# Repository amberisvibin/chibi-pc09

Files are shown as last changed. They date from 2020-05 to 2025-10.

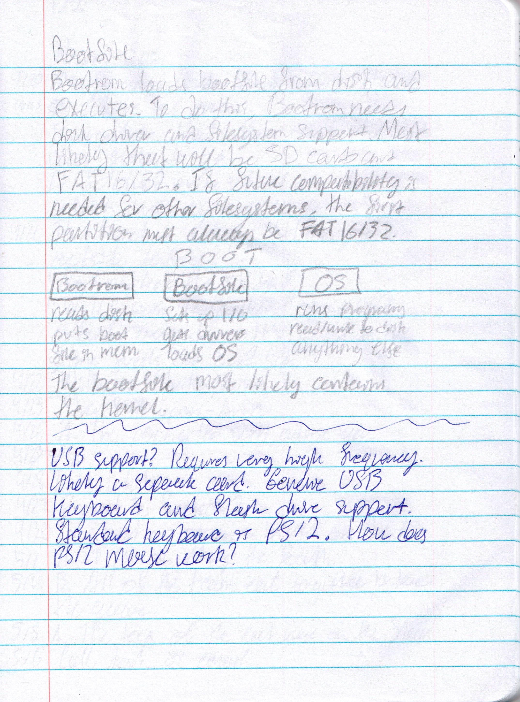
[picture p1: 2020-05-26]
docs/design notes/BR_Z800005.jpg

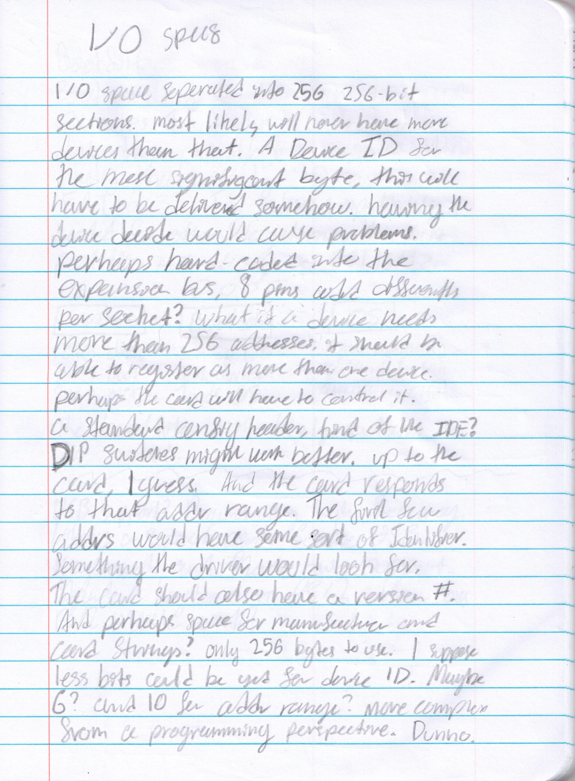
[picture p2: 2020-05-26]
docs/design notes/BR_Z800004.jpg

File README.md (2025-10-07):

# chibi pc-09

## Archived!

This repo has been archived, and the different parts have been migrated to other repos.

The PCB for prototype 1 has been moved to https://gitea.ambersplace.net/chibi/pc09-prototype-1

The firmware has been moved to https://gitea.ambersplace.net/chibi/chibi-firmware




## Description

The PC-09 will be a 6309 based microcomputer with an MMU using 74HC670 register files and dual 16550 UARTs. The plan is to eventually add uPD7220 graphics and PS/2 mouse and keyboard.

The two 74HC670s will take the top 4 bits of the address bus and expand them to 8 bits, turning the 16 bit cpu address space into a 20 bit address space capable of addressing 1MB of memory. Memory pages are 4KB. Being a register file, any page can be mapped to any slot, allowing complex memory management schemes.

The 16550 UART is capable of interrupt driven operation with FIFOs, allowing for characters to be processed in batches rather than individually, minimizing task switch delays. They also support hardware flow control, and some versions can automatically assert RTS when the FIFO is nearing full.

The uPD7220 graphics are very powerful, allowing 16 colors at 640x480, but it is a complex chip to get working. It will be left for a later date.

The solution for PS/2 keyboard and mouse have not yet been decided.

## Progress

I had started wiring together a board for prototyping, but it was destroyed in hurricane Helene. I am now recreating it in schematic form in order to order a PCB.

Prototype 1 is currently in progress. It will be a much simpler system. It will have no MMU, just the CPU, some RAM, some ROM, and the UART.

The PCB and parts for Prototype #1 have been ordered, and assembly will begin soon. Initial test code is now available in the code/ directory.

Assembly is in progress.

## License

This project is licensed under the MIT license. This applies to both the hardware (schematics, bill of materials, pcb layouts) and documentation. This does *not* apply to the datasheets/ directory or code/assist09/. Those files belong to their respective copyright holders.

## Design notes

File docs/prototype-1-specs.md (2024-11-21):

# 6309 Board Prototype #1 Specs

HD63C09 CPU @ 3MHz
AS6C62256-55 SRAM (32KB)
SST39SF010A-70 FLASH (32KB Used)
PC16550 UART @ 1.8342MHz

## Memory Map

| Device | Location  |
|---|---|
| FLASH  | 8000-FFFF |
| UART | 7F00-7FFF |
| SRAM | 0000-7EFF |

## Truth Table

| A15 | A14-A9 | A8 | Chip |
|-----|---|----|---|
| H | x | x  | FLASH  |
| L | x | L  | SRAM |
| L | H | H  | UART |

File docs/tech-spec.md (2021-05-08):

# CHIBI PC-09 Technical Specification

5-17-21 Amber Zeller

## Quick Specs

#### CPU

1, 1.5, 2 MHz Motorola 6809

#### Memory

64k SRAM on external card for optional MMU capability. Seperated into 2k blocks, numbered 0-31. Only 62k of memory is accessible, due to the I/O block.

#### I/O

2k block, position 30. Addresses EFFF-F7FE. Further subdivided into 128 devices of 16 addresses each. 

## Address Space Diagram

| Address Range | Description |
| --- | --- |
| 0000 - 07FF | Kernal Root Block |
| 0800 - EFFE | Standard Memory Blocks |
| EFFF - F7FE | I/O Block |
| F7FF - FFFF | Vector Block |

## I/O Block Description

11 bits per block

128 devices are possible, though will likely never be used. 

| Bits | Description |
| ---- | --- |
| 0-6  | Device selection  |
| 7-10 | Address selection |

## Expansion Card Description

Byte 0 of every card should contain a descriptor. The structure of the descriptor is described in the following table.

| Bits | Descriptor |
| ---- | --- |
| 0-2  | Type |

### Type Descriptor Table

| Type Descriptor | Description | Example  |
| --- | --- | --- |
| 000 | Block Storage | SD Card  |
| 001 | ANSI I/O Stream | UART |
| 010 | ANSI Compatible Graphics Device | VGA64 |
| 011 | Input Device | Keyboard |
| 1xx | Other | Other |

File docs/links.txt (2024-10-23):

uPD7220 graphics card
https://hackaday.io/project/164728/logs

16550 to 6502
https://www.cs.cornell.edu/~kt/post/6502-5/

VT82C42 to 65816
http://www.baltissen.org/newhtm/65816atx.htm

6502.org post about CMOS/TTL driving voltage
http://forum.6502.org/viewtopic.php?f=4&t=3477

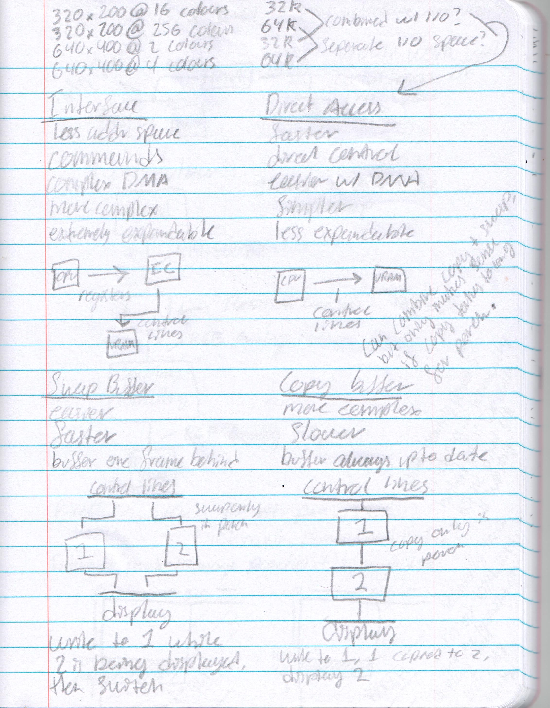
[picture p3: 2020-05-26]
docs/design notes/BR_Z80.jpg

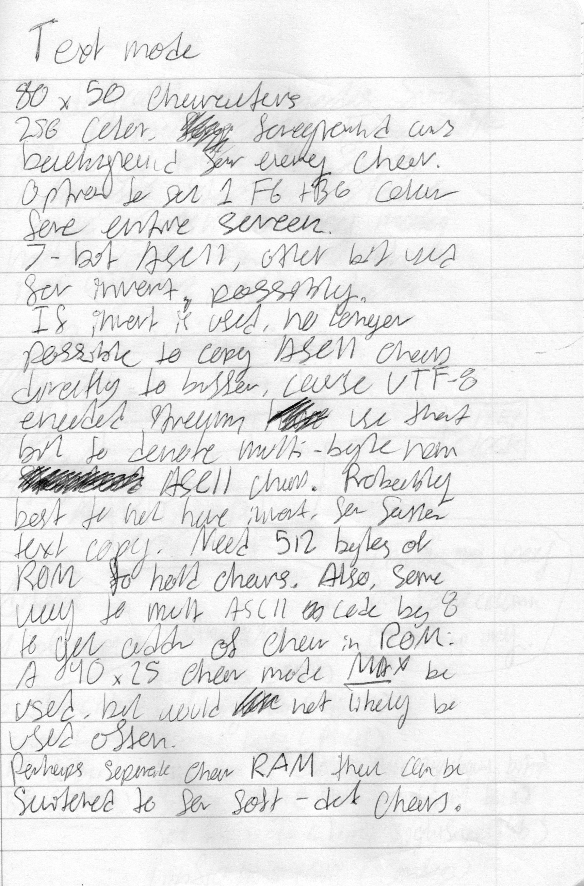
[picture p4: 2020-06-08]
docs/design notes/BR_Z800006.jpg

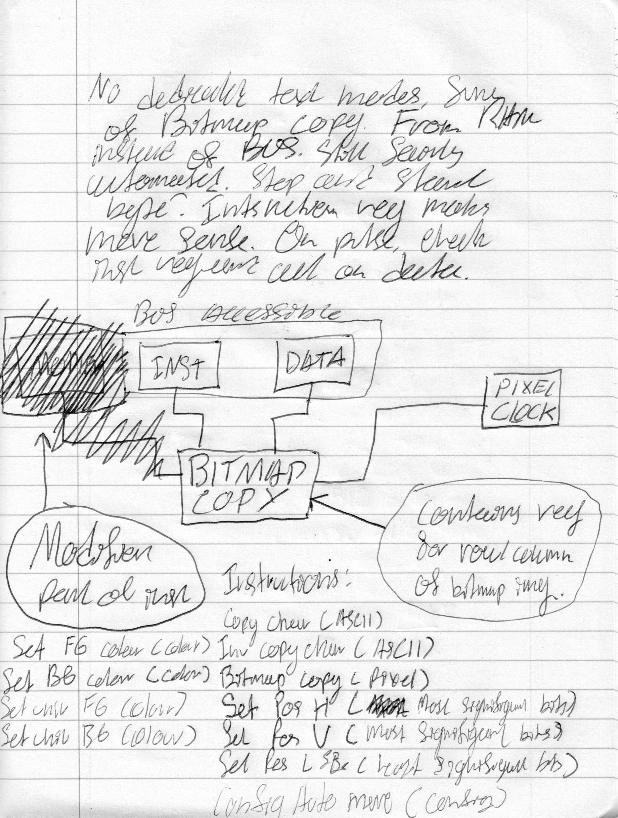
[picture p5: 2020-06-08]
docs/design notes/BR_Z800007.jpg

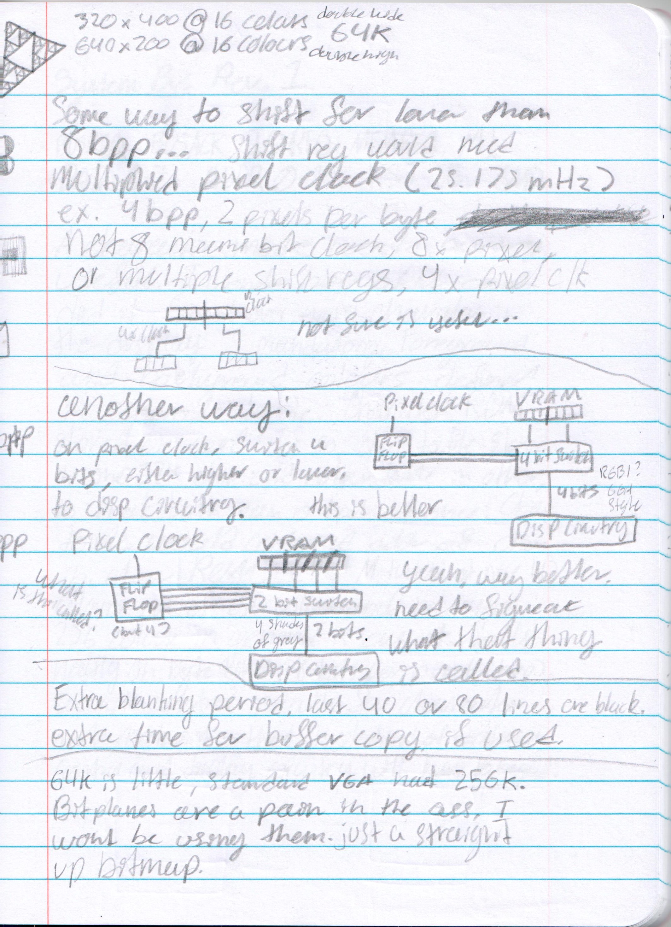
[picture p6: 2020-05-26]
docs/design notes/BR_Z800002.jpg

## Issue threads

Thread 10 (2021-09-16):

mpl does not fit

amberisvibin, 2021-09-16:
this issue will act as a repo for MPL licensing issues

### problems:

- MPL doesnt apply well to schematics and open source hardware
- need to determine how to do documentation license
- MPL must be applied on a file-by-file level (less important)

### potential solutions:

- separate licenses for different parts
- split into multiple repos

amberisvibin, 2024-10-22:
fixed in #cb9a218

Closed 2024-10-22.

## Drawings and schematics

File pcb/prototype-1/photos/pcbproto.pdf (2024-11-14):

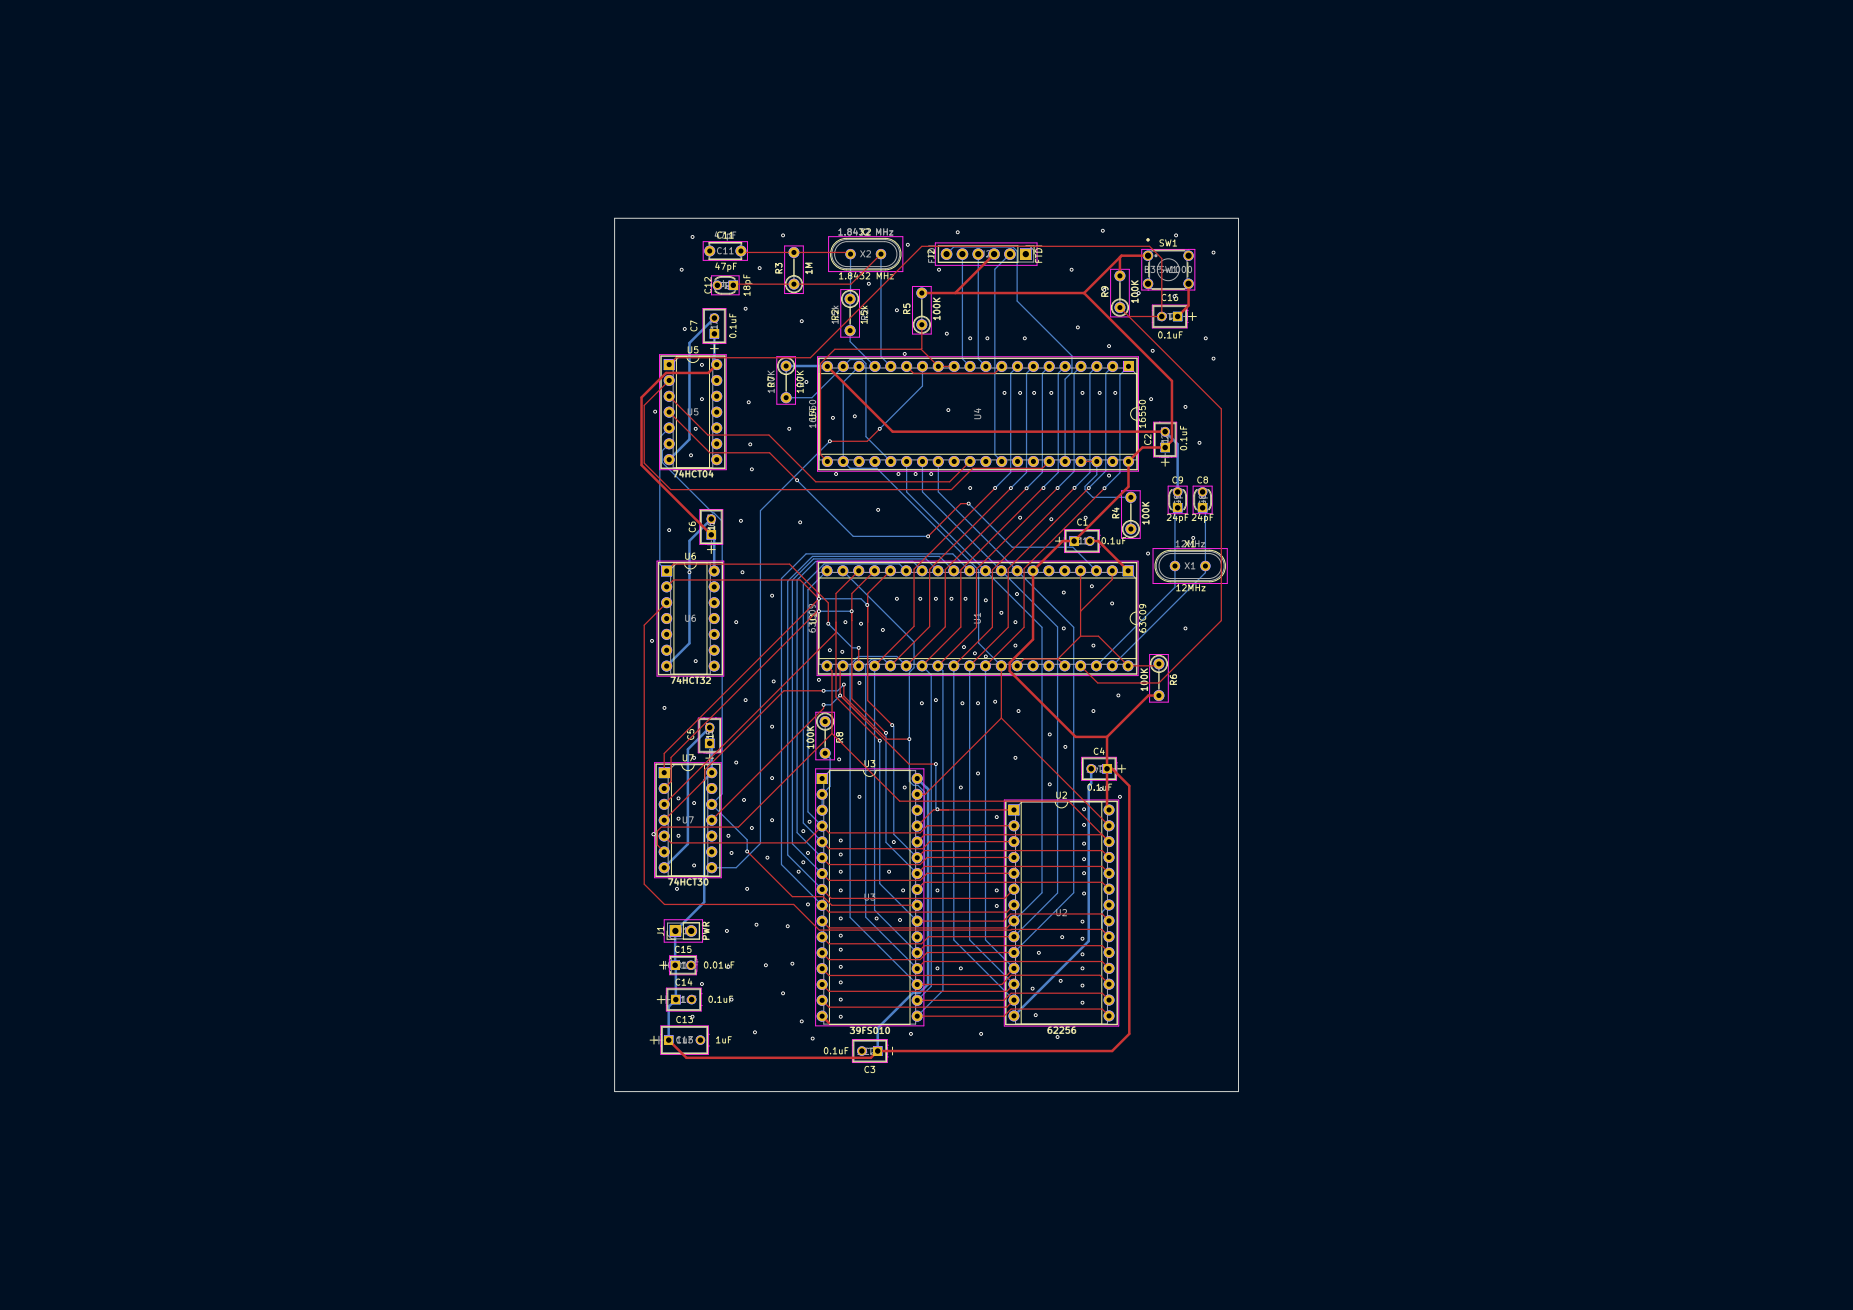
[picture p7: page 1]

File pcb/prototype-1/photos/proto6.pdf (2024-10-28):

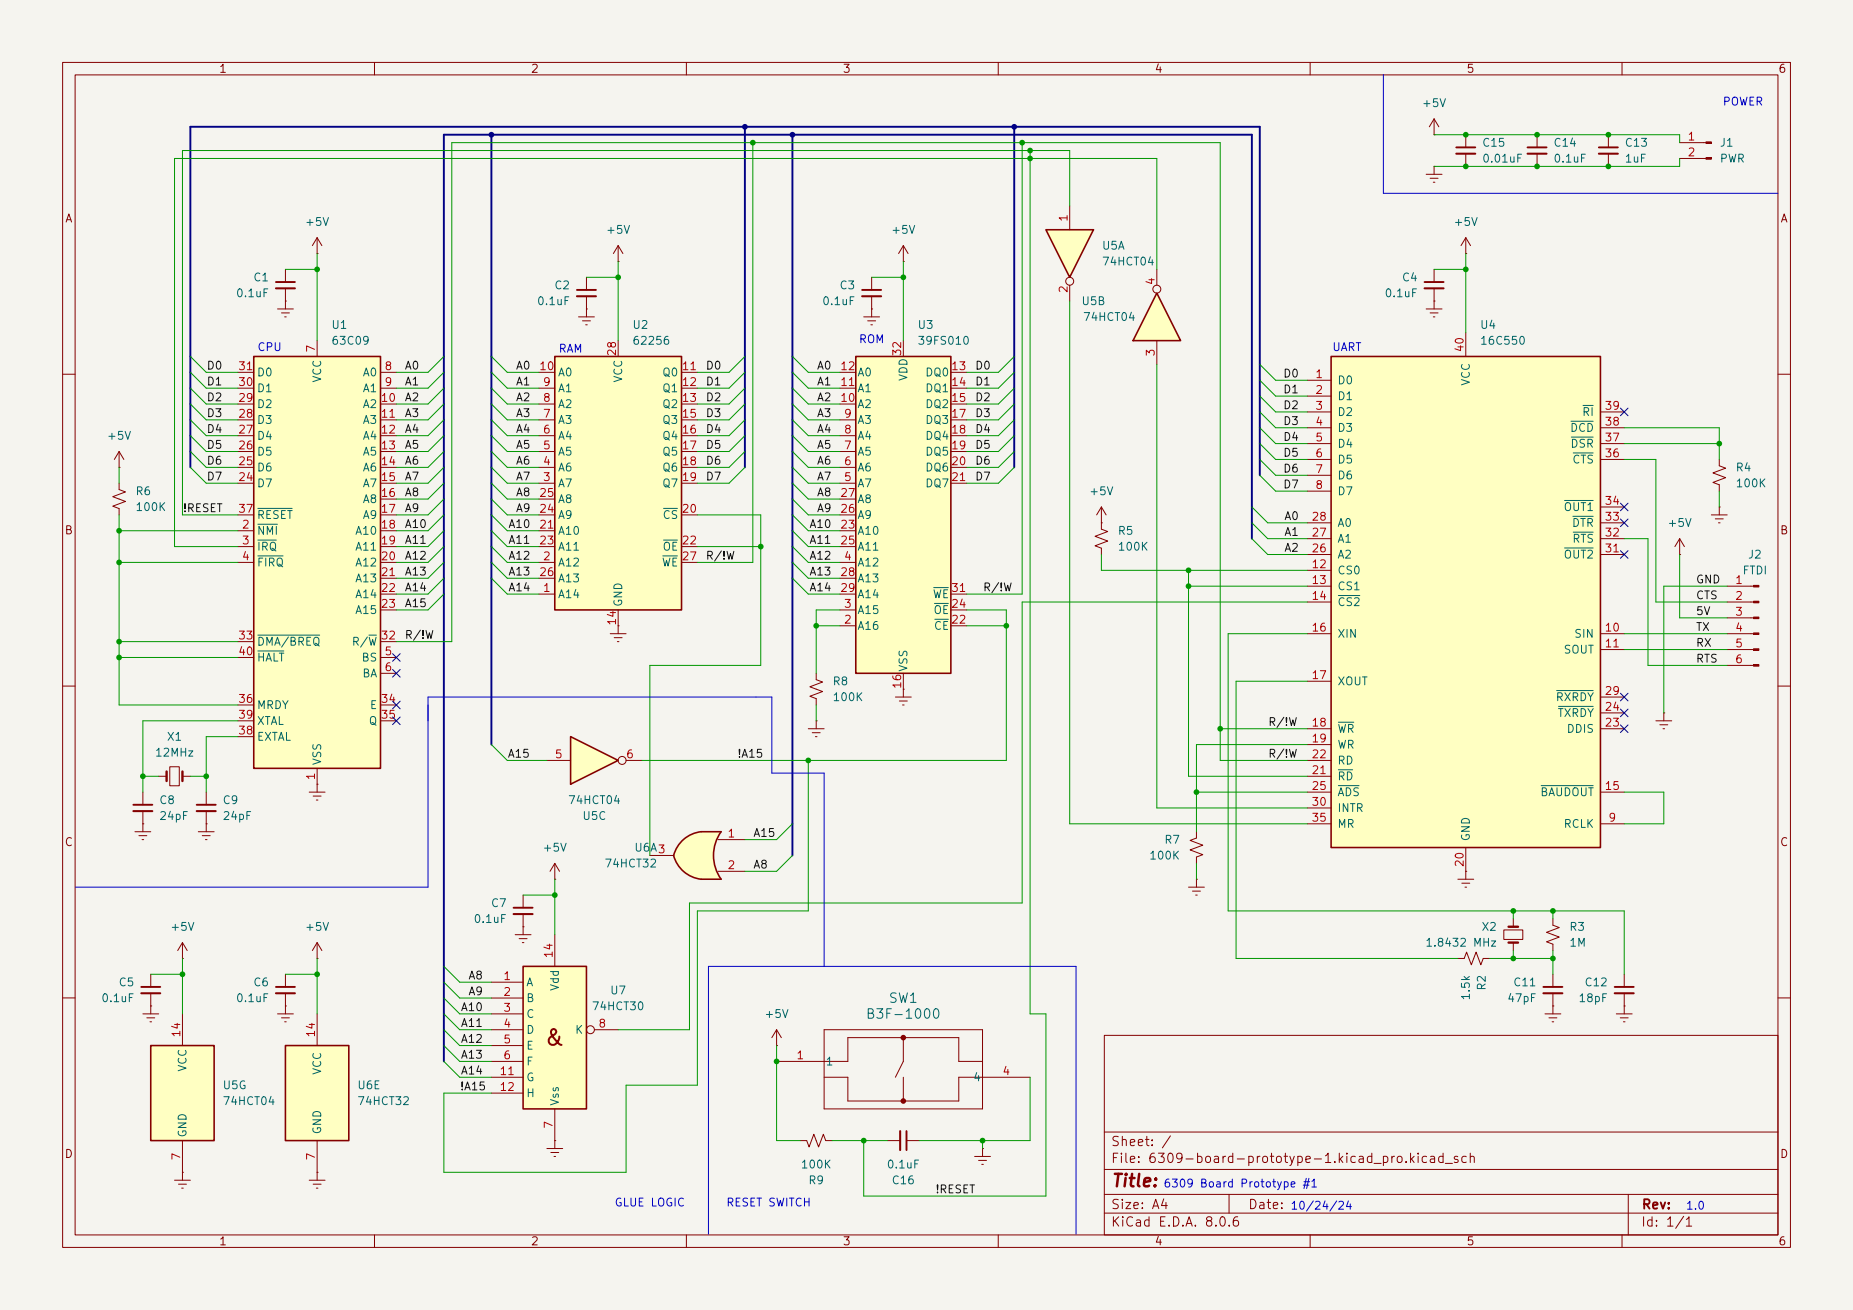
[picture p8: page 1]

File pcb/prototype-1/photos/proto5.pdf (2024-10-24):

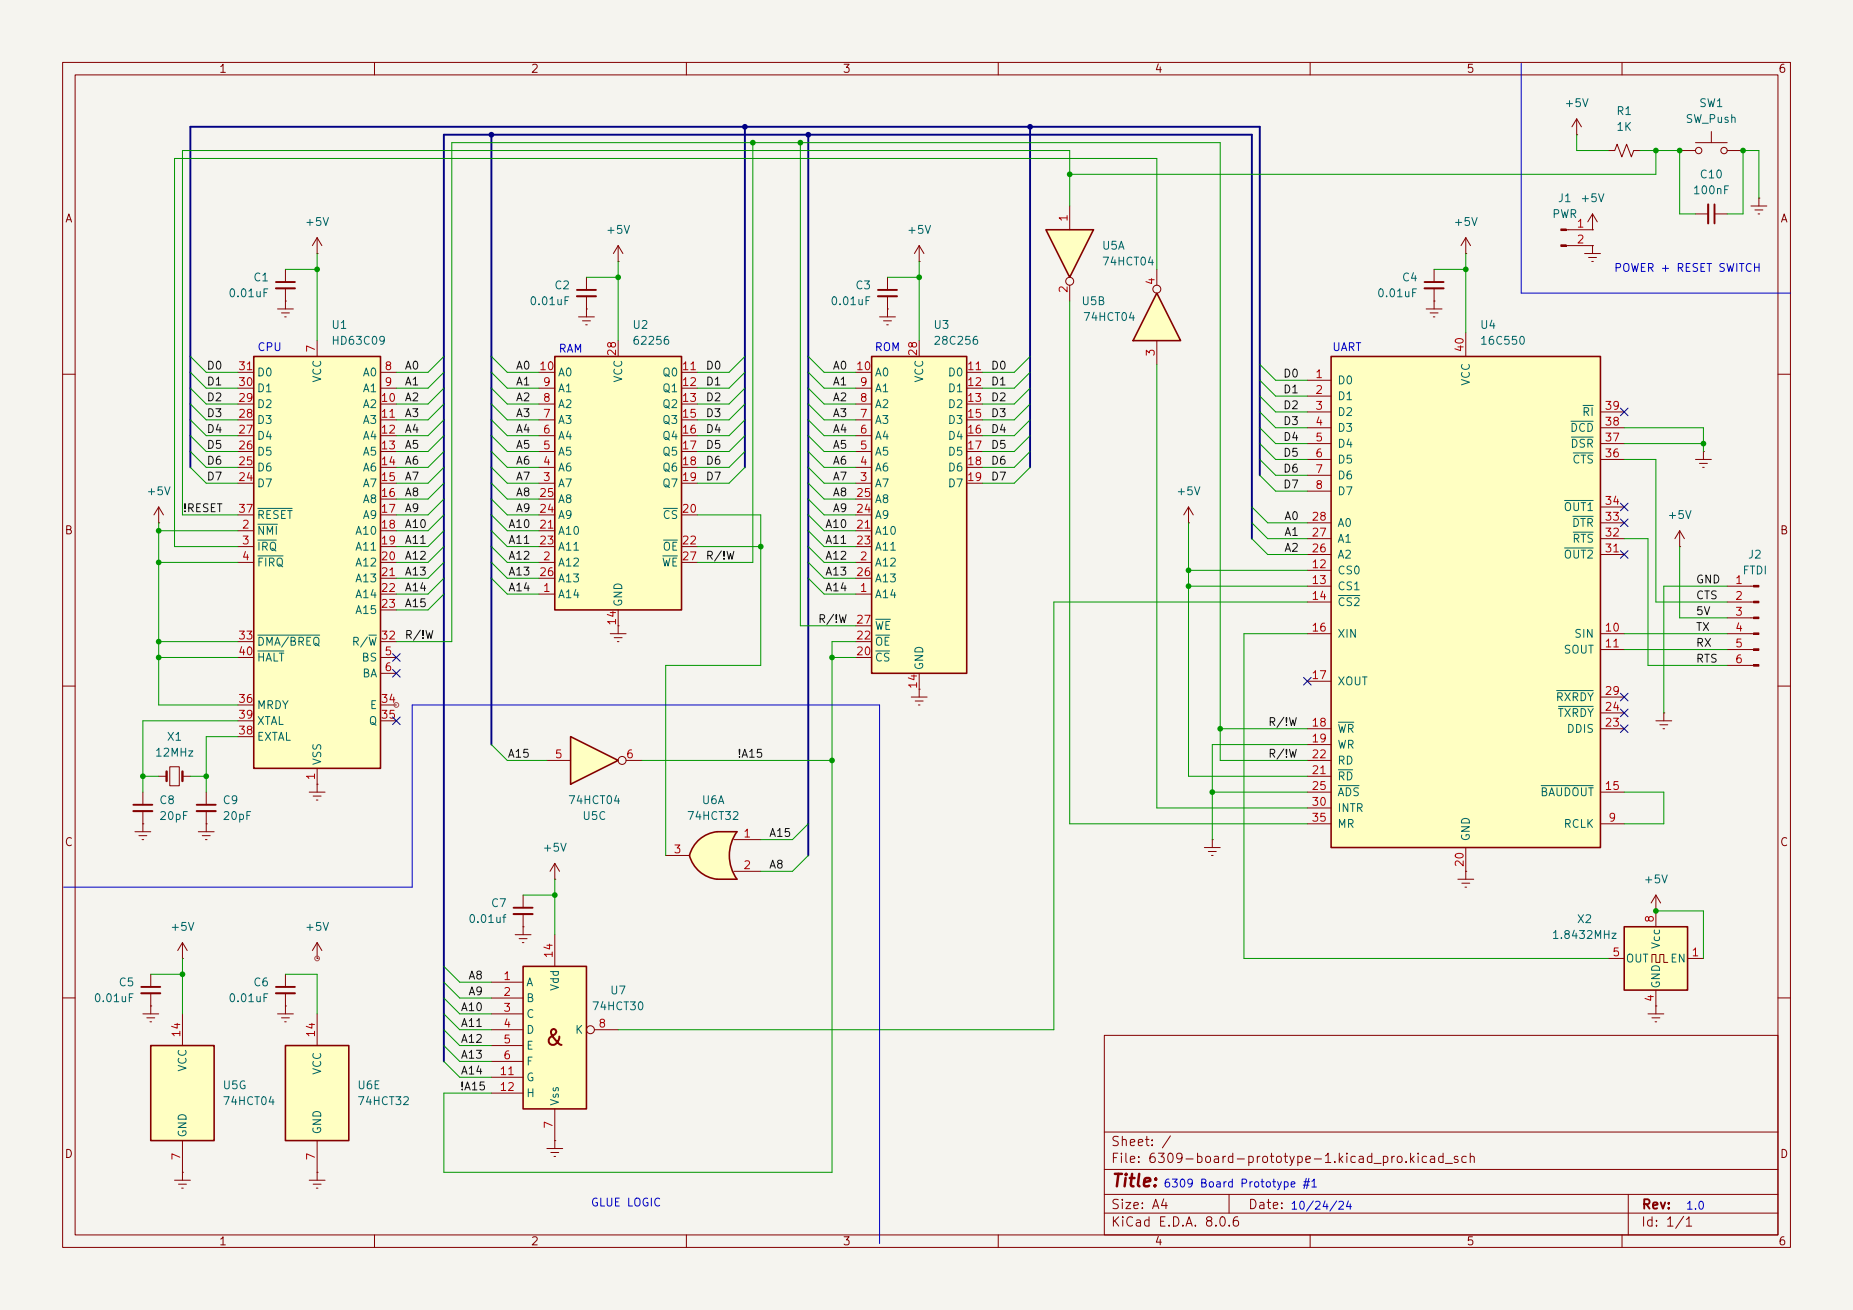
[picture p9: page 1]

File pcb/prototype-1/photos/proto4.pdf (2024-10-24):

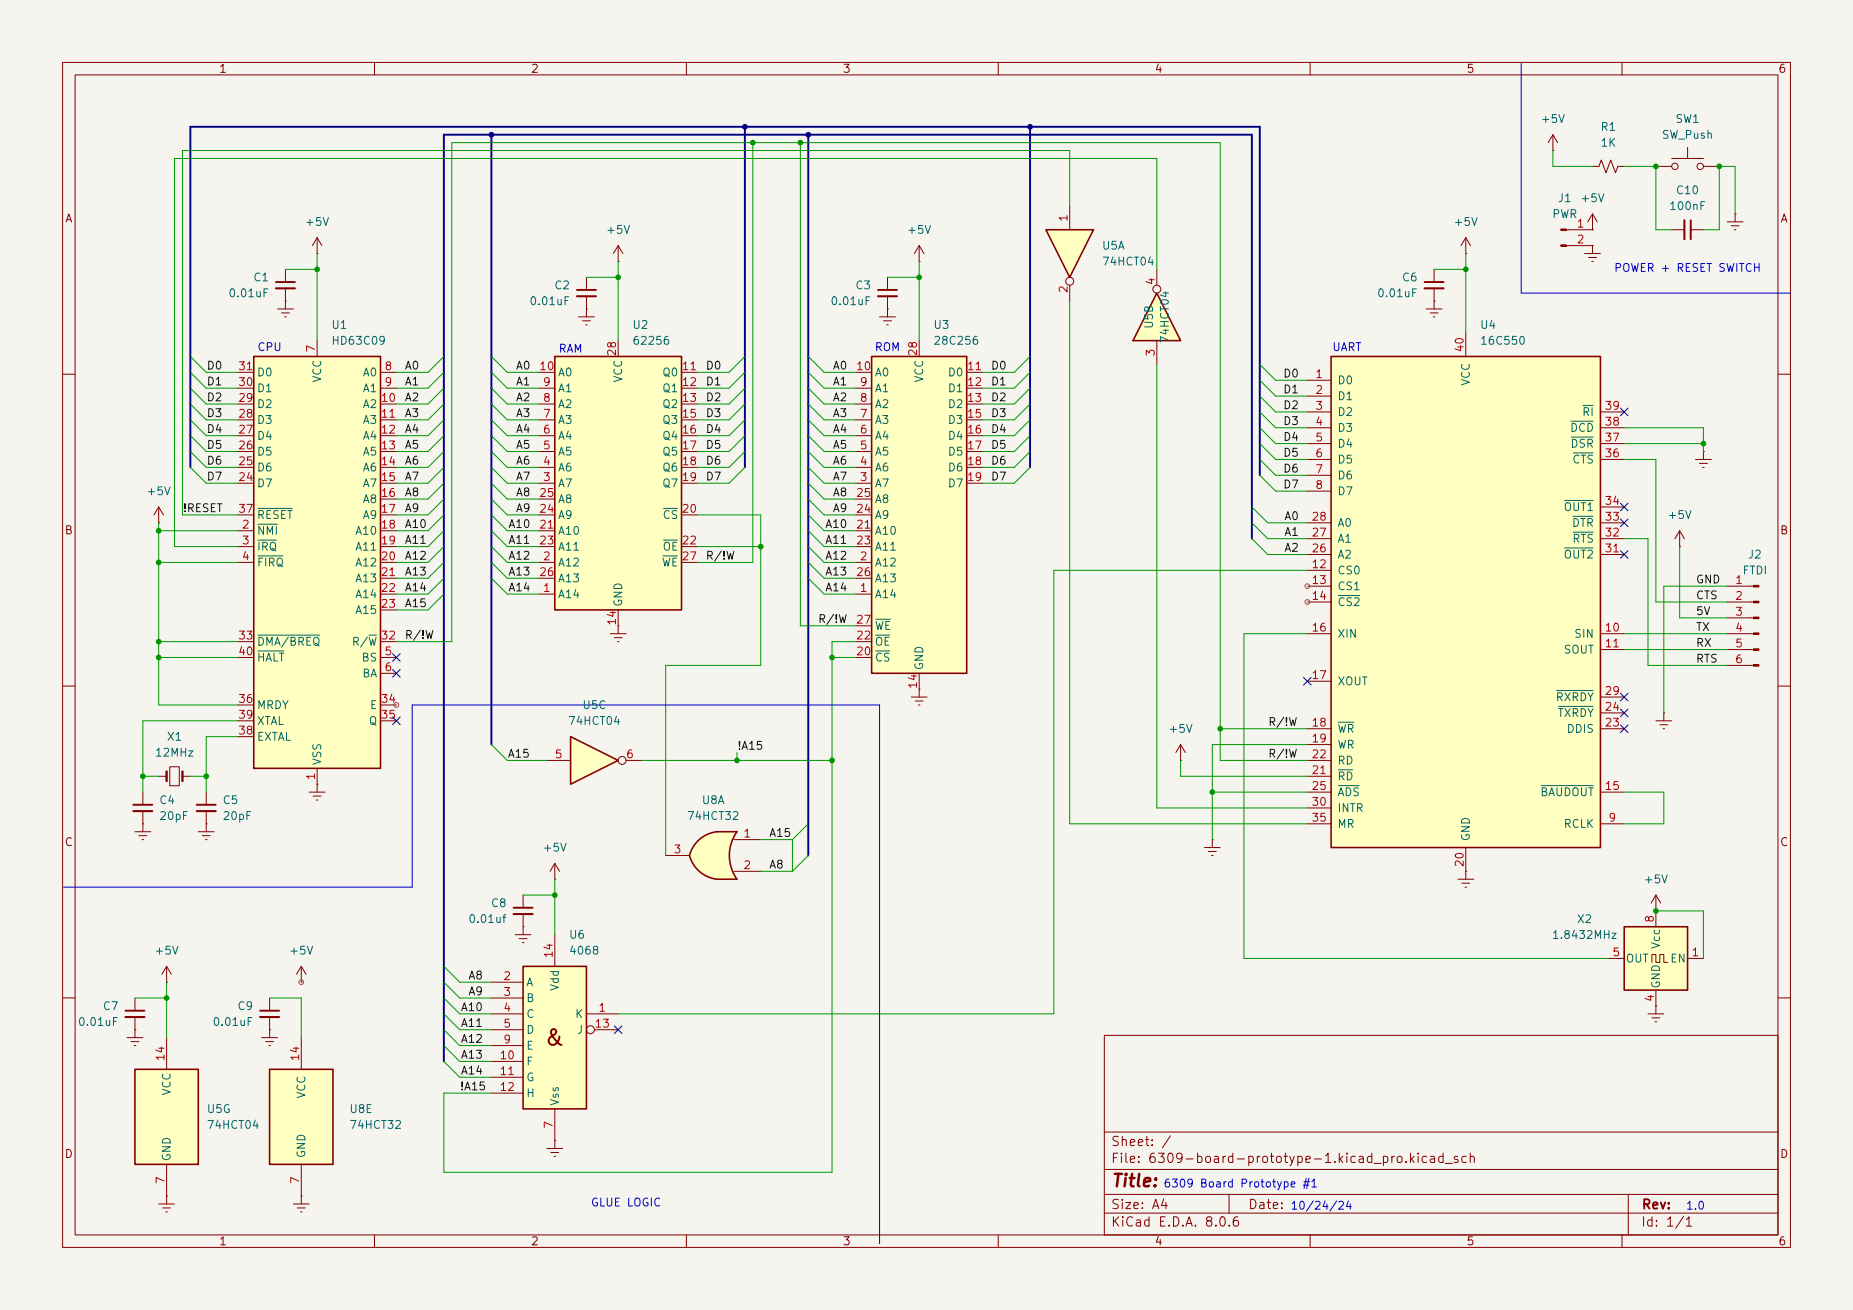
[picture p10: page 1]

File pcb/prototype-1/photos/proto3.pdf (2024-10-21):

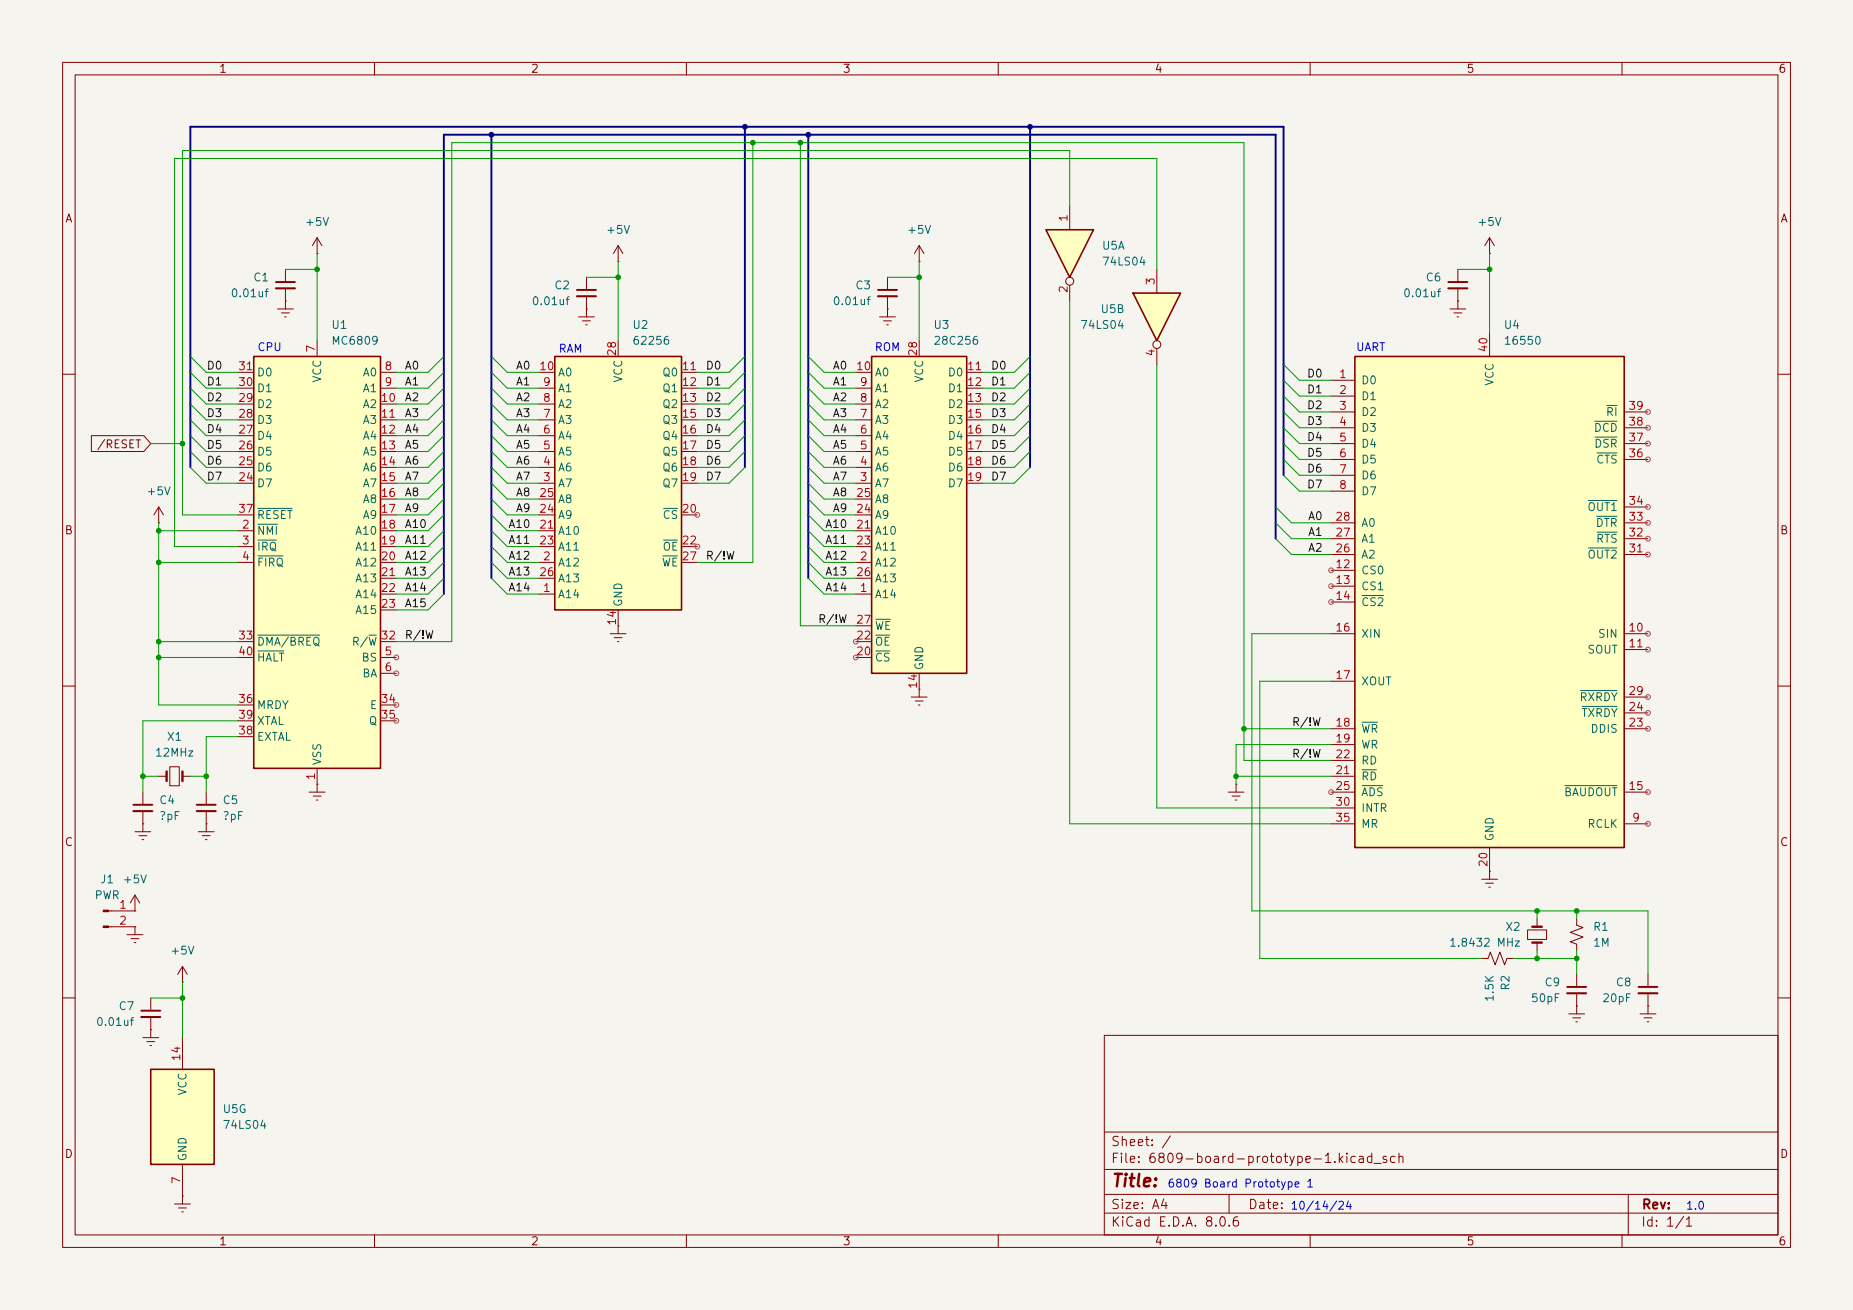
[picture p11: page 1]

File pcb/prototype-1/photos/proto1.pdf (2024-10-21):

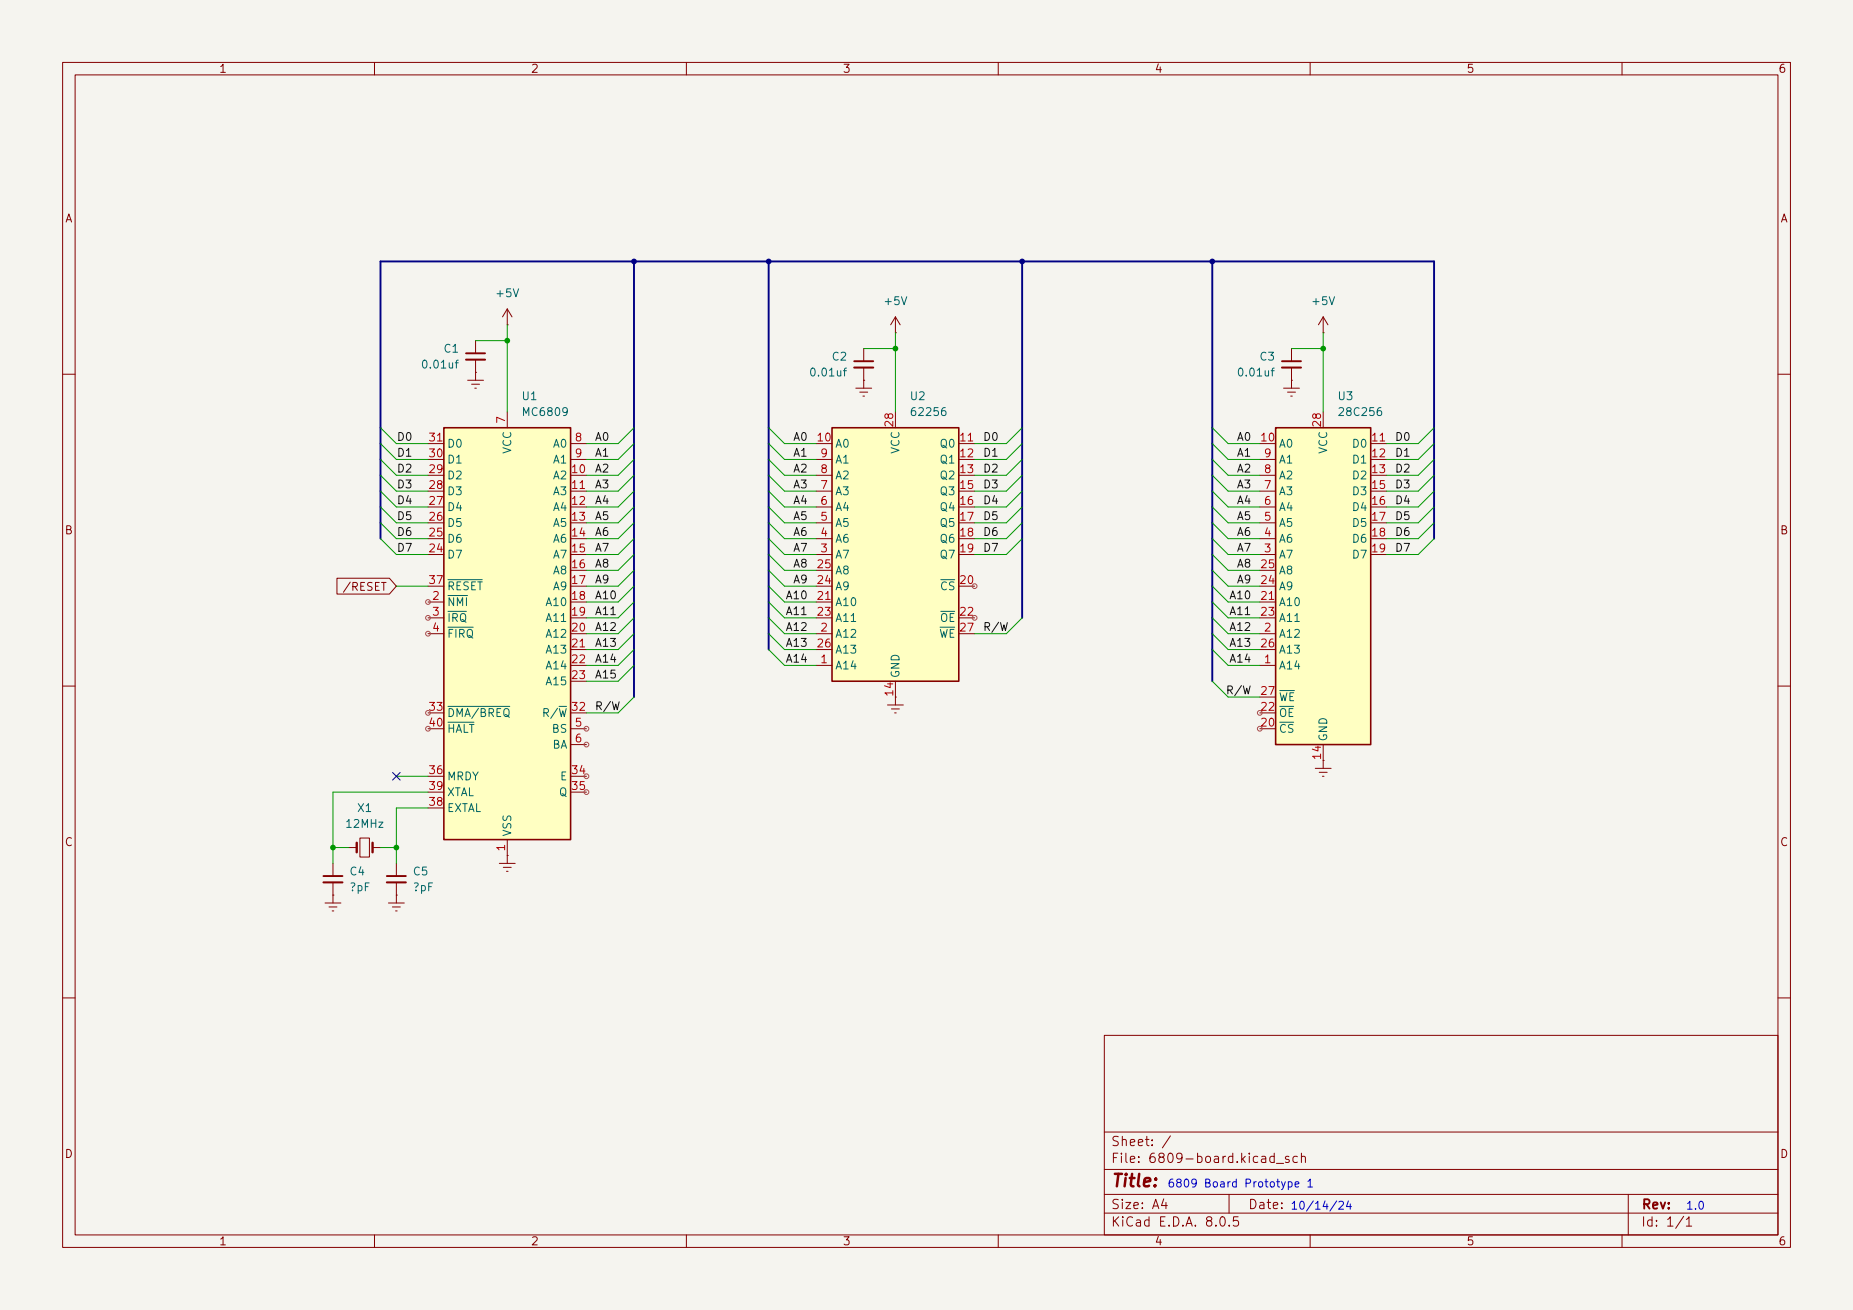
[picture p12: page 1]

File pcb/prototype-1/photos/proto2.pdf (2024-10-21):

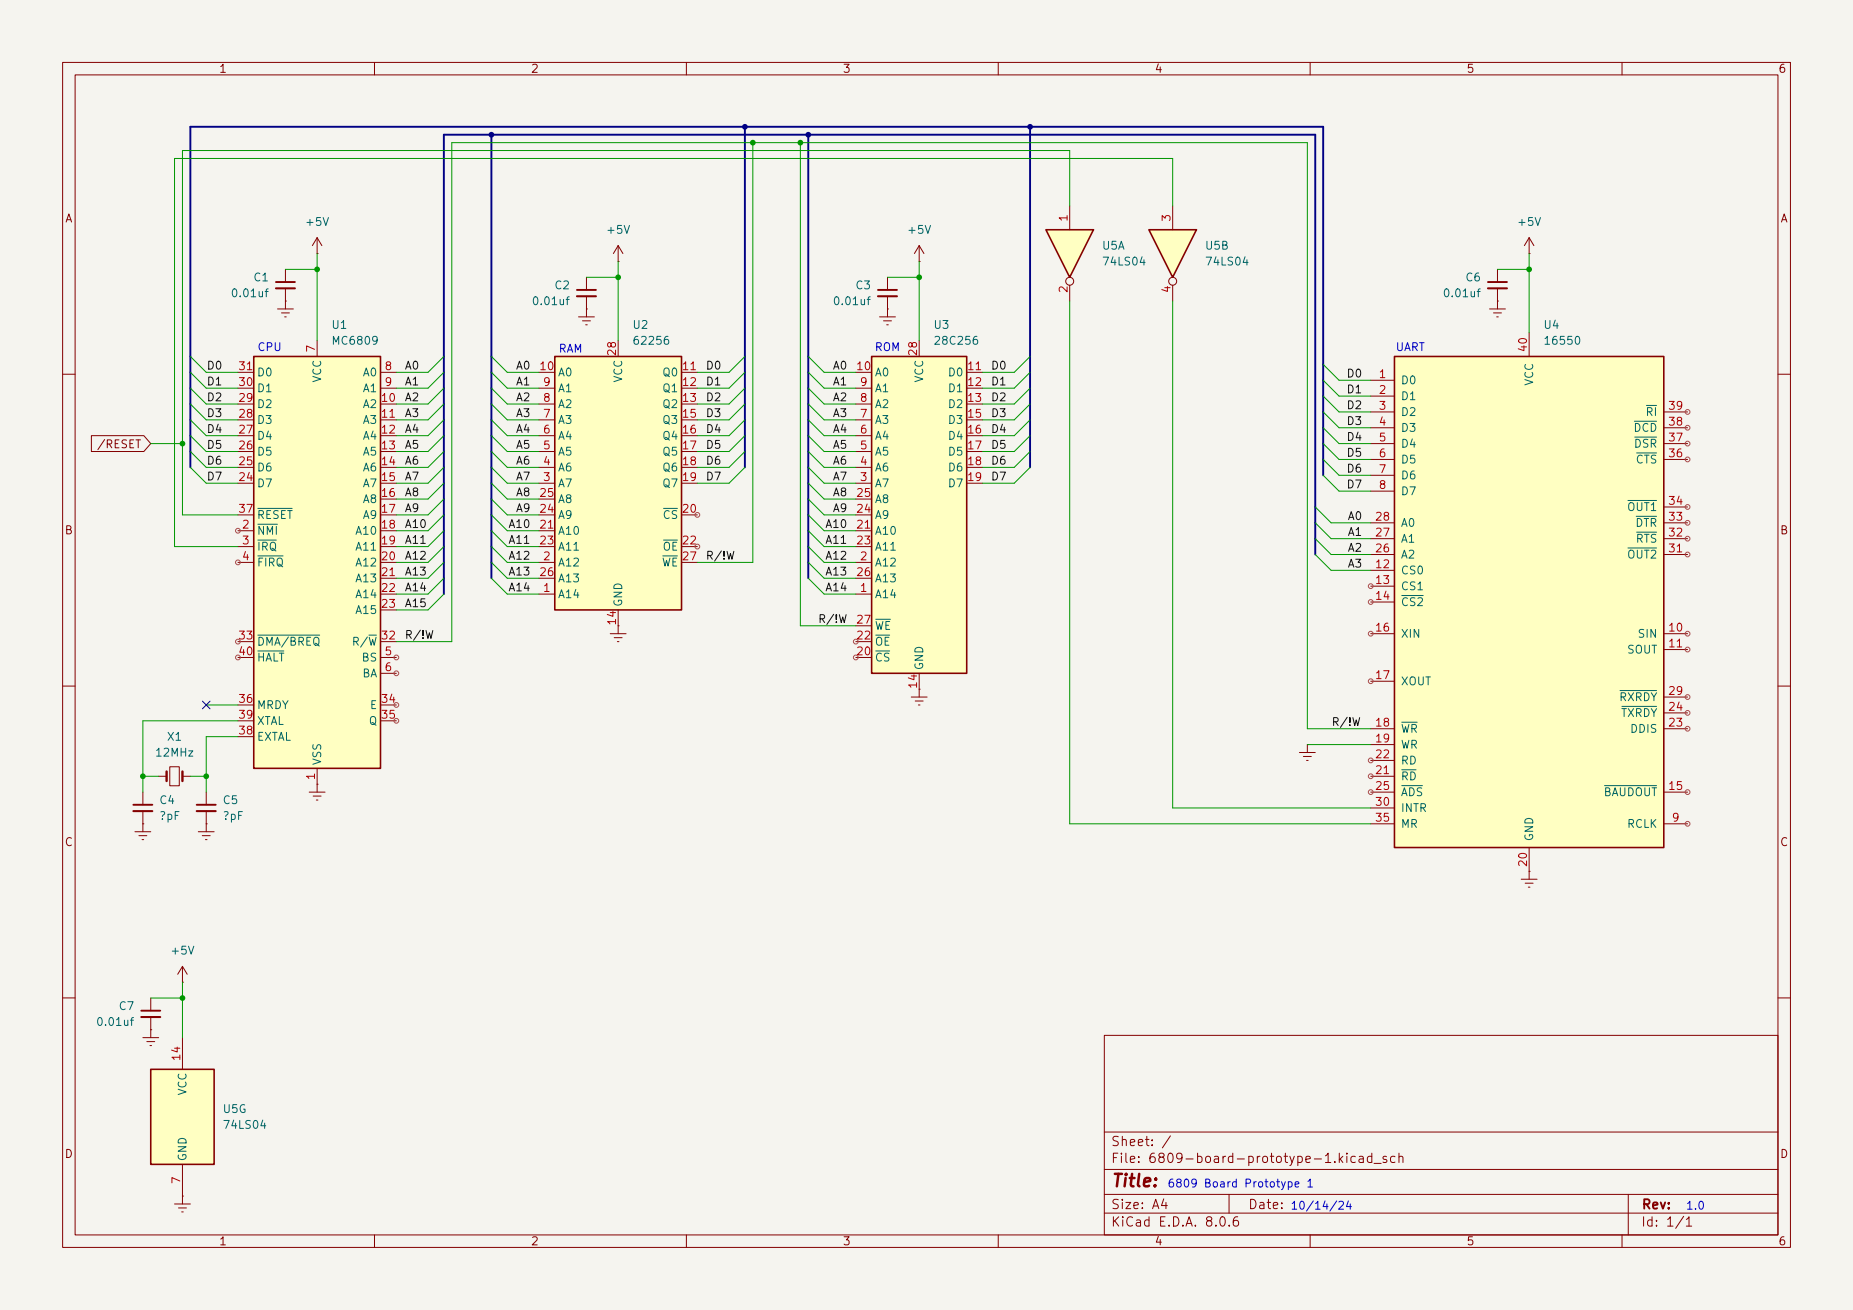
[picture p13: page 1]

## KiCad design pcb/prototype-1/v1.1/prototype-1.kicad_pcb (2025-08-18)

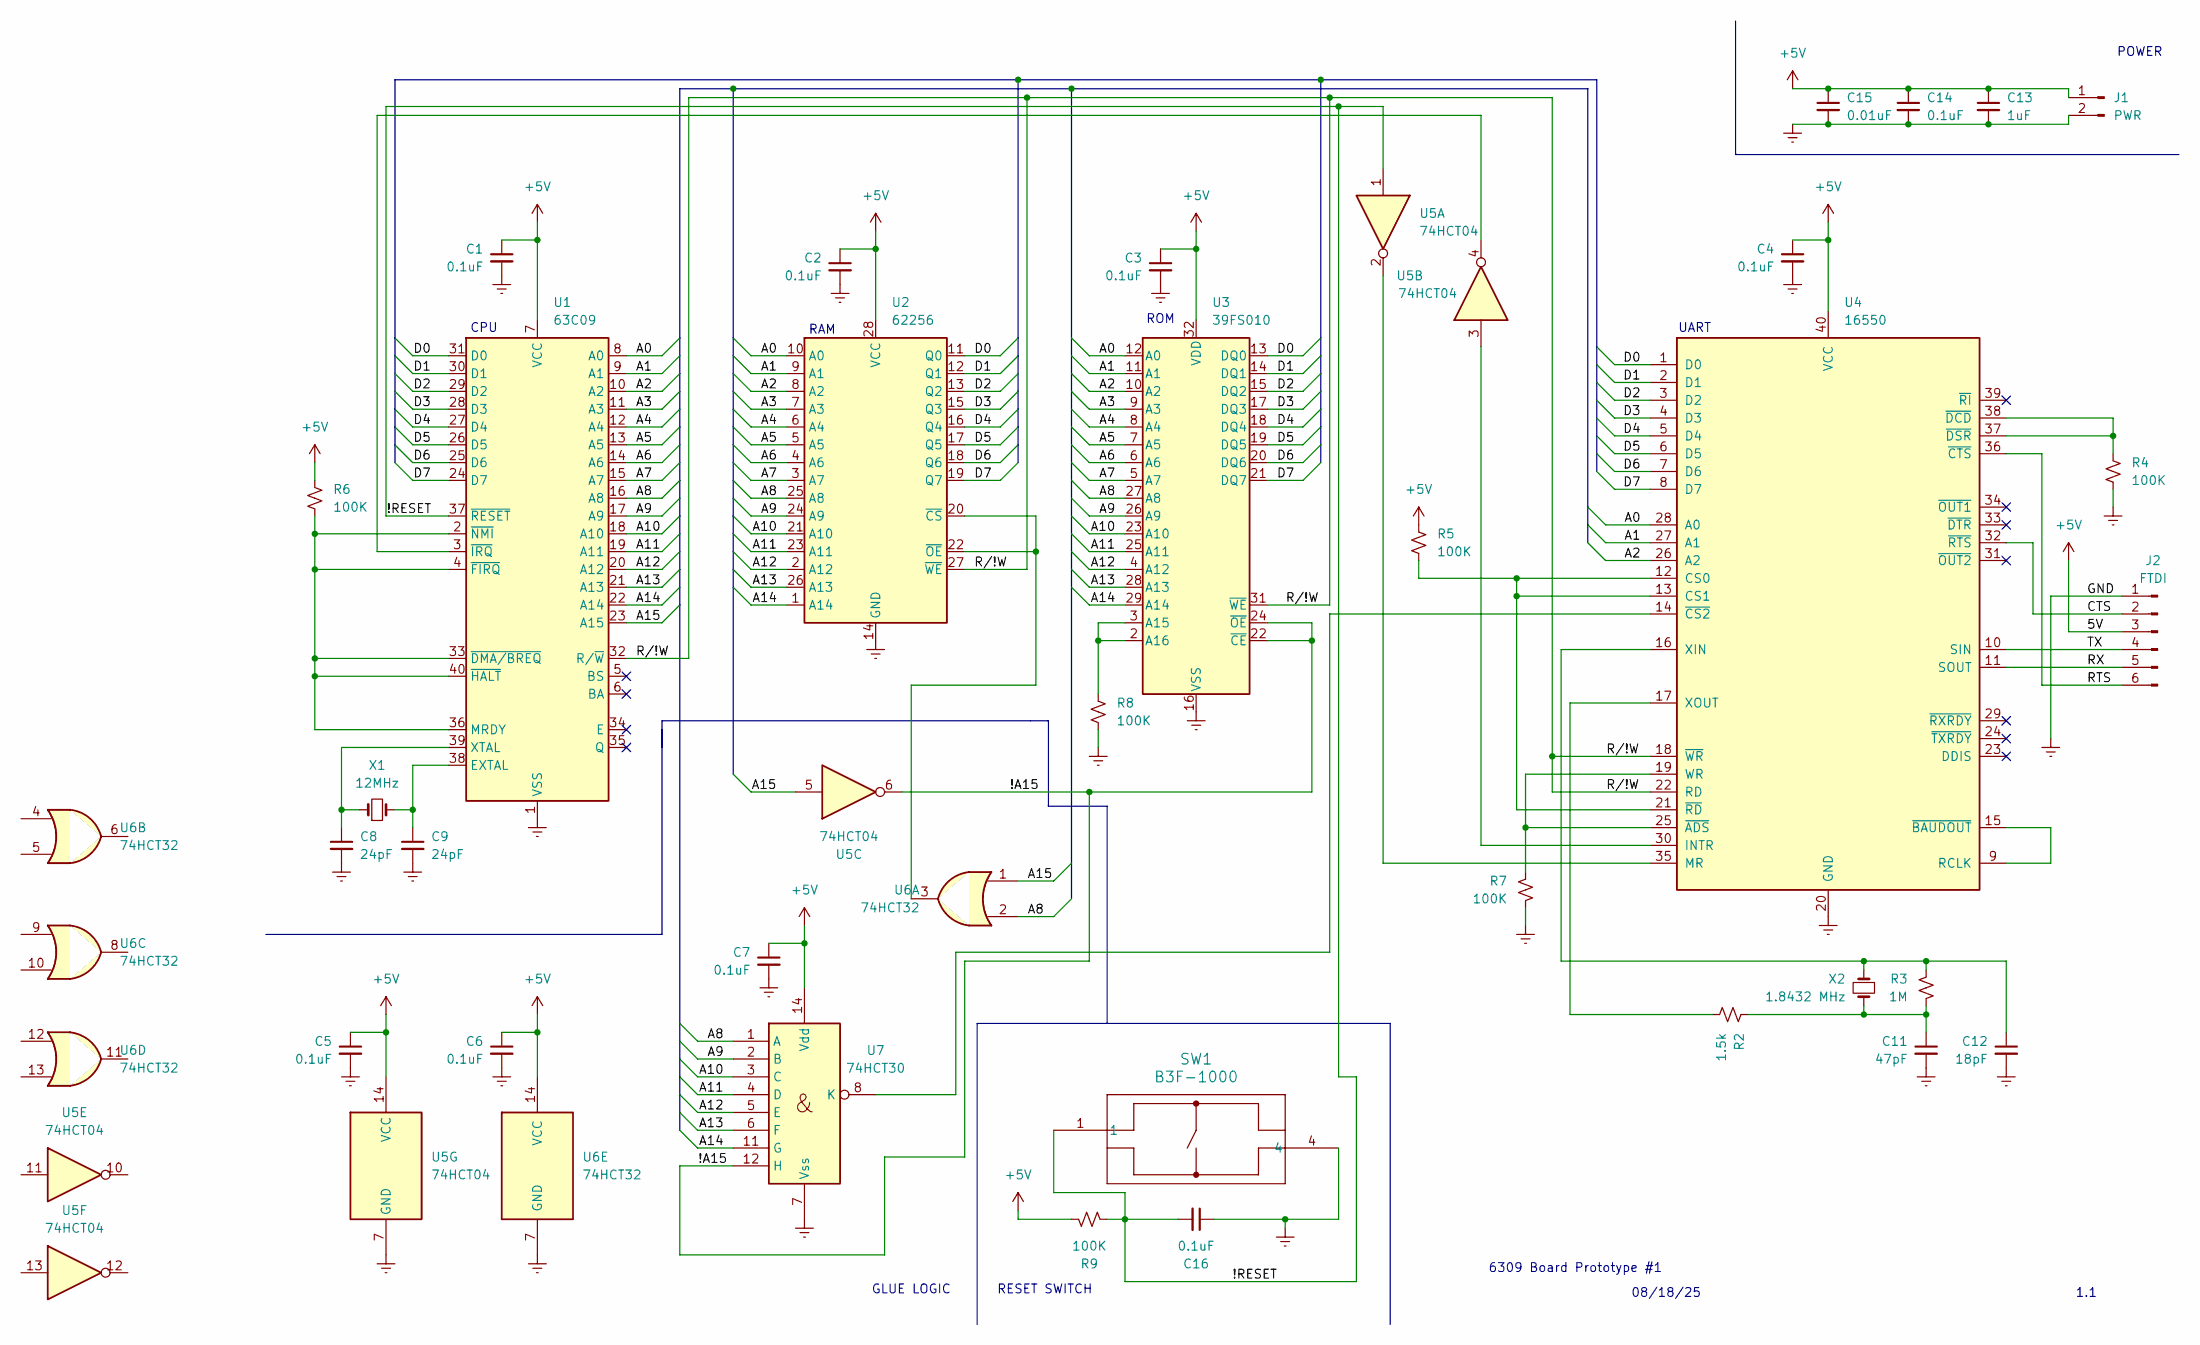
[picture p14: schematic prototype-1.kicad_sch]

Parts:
C1, C2, C3, C4, C5, C6, C7, C14, C16: 0.1uF; CAP_C320C_MR_X7R_KEM
C8, C9: 24pF; CAP_C317_KEM
C11: 47pF; C_Disc_D5.0mm_W2.5mm_P5.00mm
C12: 18pF; CAP_C317_KEM
C13: 1uF; CAP_C330C_MR_X7R_KEM
C15: 0.01uF; CAP_C315C_MR_X7R_KEM
J1: PWR; PinHeader_1x02_P2.54mm_Vertical
J2: FTDI; PinHeader_1x06_P2.54mm_Vertical
R2: 1.5k; R_Axial_DIN0207_L6.3mm_D2.5mm_P5.08mm_Vertical
R3: 1M; R_Axial_DIN0207_L6.3mm_D2.5mm_P5.08mm_Vertical
R4, R5, R6, R7, R8, R9: 100K; R_Axial_DIN0207_L6.3mm_D2.5mm_P5.08mm_Vertical
SW1: B3F-1000; SW_B3F-1000_OMR
U1: 63C09; DIP-40_W15.24mm_Socket
U2: 62256; DIP-28_W15.24mm_Socket
U3: 39FS010; DIP-32_W15.24mm
U4: 16550; DIP-40_W15.24mm_Socket
U5: 74HCT04; DIP-14_W7.62mm_Socket
U6: 74HCT32; DIP-14_W7.62mm_Socket
U7: 74HCT30; DIP-14_W7.62mm_Socket
X1: 12MHz; Crystal_HC49-U_Vertical
X2: 1.8432 MHz; Crystal_HC49-U_Vertical

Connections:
+5V: C1.1, C2.1, C3.1, C4.1, C5.1, C6.1, C7.1, C13.1, C14.1, C15.1, J1.1, J2.3, R5.2, R6.2, R9.2, U1.7 (VCC), U2.28 (VCC), U3.32 (VDD), U4.40 (VCC), U5.14 (VCC), U6.14 (VCC), U7.14 (Vdd)
/!A15: U3.22 (~CE), U3.24 (~OE), U5.6, U7.12 (H)
/!RESET: C16.2, R9.1, SW1.1, U1.37 (~RESET), U5.1
/A0: U1.8 (A0), U2.10 (A0), U3.12 (A0), U4.28 (A0)
/A1: U1.9 (A1), U2.9 (A1), U3.11 (A1), U4.27 (A1)
/A2: U1.10 (A2), U2.8 (A2), U3.10 (A2), U4.26 (A2)
/A3: U1.11 (A3), U2.7 (A3), U3.9 (A3)
/A4: U1.12 (A4), U2.6 (A4), U3.8 (A4)
/A5: U1.13 (A5), U2.5 (A5), U3.7 (A5)
/A6: U1.14 (A6), U2.4 (A6), U3.6 (A6)
/A7: U1.15 (A7), U2.3 (A7), U3.5 (A7)
/A8: U1.16 (A8), U2.25 (A8), U3.27 (A8), U6.2, U7.1 (A)
/A9: U1.17 (A9), U2.24 (A9), U3.26 (A9), U7.2 (B)
/A10: U1.18 (A10), U2.21 (A10), U3.23 (A10), U7.3 (C)
/A11: U1.19 (A11), U2.23 (A11), U3.25 (A11), U7.4 (D)
/A12: U1.20 (A12), U2.2 (A12), U3.4 (A12), U7.5 (E)
/A13: U1.21 (A13), U2.26 (A13), U3.28 (A13), U7.6 (F)
/A14: U1.22 (A14), U2.1 (A14), U3.29 (A14), U7.11 (G)
/A15: U1.23 (A15), U5.5, U6.1
/CTS: J2.2, U4.32 (~RTS)
/D0: U1.31 (D0), U2.11 (Q0), U3.13 (DQ0), U4.1 (D0)
/D1: U1.30 (D1), U2.12 (Q1), U3.14 (DQ1), U4.2 (D1)
/D2: U1.29 (D2), U2.13 (Q2), U3.15 (DQ2), U4.3 (D2)
/D3: U1.28 (D3), U2.15 (Q3), U3.17 (DQ3), U4.4 (D3)
/D4: U1.27 (D4), U2.16 (Q4), U3.18 (DQ4), U4.5 (D4)
/D5: U1.26 (D5), U2.17 (Q5), U3.19 (DQ5), U4.6 (D5)
/D6: U1.25 (D6), U2.18 (Q6), U3.20 (DQ6), U4.7 (D6)
/D7: U1.24 (D7), U2.19 (Q7), U3.21 (DQ7), U4.8 (D7)
/RTS: J2.6, U4.36 (~CTS)
/RX: J2.5, U4.11 (SOUT)
/R/!W: U1.32 (R/~W), U2.27 (~WE), U3.31 (~WE), U4.18 (~WR), U4.22 (RD)
/TX: J2.4, U4.10 (SIN)
GND: C1.2, C2.2, C3.2, C4.2, C5.2, C6.2, C7.2, C8.2, C9.2, C11.2, C12.2, C13.2, C14.2, C15.2, C16.1, J1.2, J2.1, R4.1, R7.1, R8.1, SW1.4, U1.1 (VSS), U2.14 (GND), U3.16 (VSS), U4.20 (GND), U5.7 (GND), U6.7 (GND), U7.7 (Vss)
unnamed: C11.1, R2.1, R3.2, X2.2
unnamed: C9.1, U1.38 (EXTAL), X1.2
unnamed: R6.1, U1.2 (~NMI), U1.4 (~FIRQ), U1.33 (~DMA/BREQ), U1.36 (MRDY), U1.40 (~HALT)
unnamed: C8.1, U1.39 (XTAL), X1.1
unnamed: U1.3 (~IRQ), U5.4
unnamed: U2.20 (~CS), U2.22 (~OE), U6.3
unnamed: R8.2, U3.2 (A16), U3.3 (A15)
unnamed: R5.1, U4.12 (CS0), U4.13 (CS1), U4.21 (~RD)
unnamed: U4.30 (INTR), U5.3
unnamed: U4.35 (MR), U5.2
unnamed: U4.9 (RCLK), U4.15 (~BAUDOUT)
unnamed: R7.2, U4.19 (WR), U4.25 (~ADS)
unnamed: C12.1, R3.1, U4.16 (XIN), X2.1
unnamed: R2.2, U4.17 (XOUT)
unnamed: U4.14 (~CS2), U7.8 (K)
unnamed: R4.2, U4.37 (~DSR), U4.38 (~DCD)

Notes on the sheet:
GLUE LOGIC
1.1
ROM
UART
CPU
RESET SWITCH
POWER
6309 Board Prototype #1
08/18/25
RAM

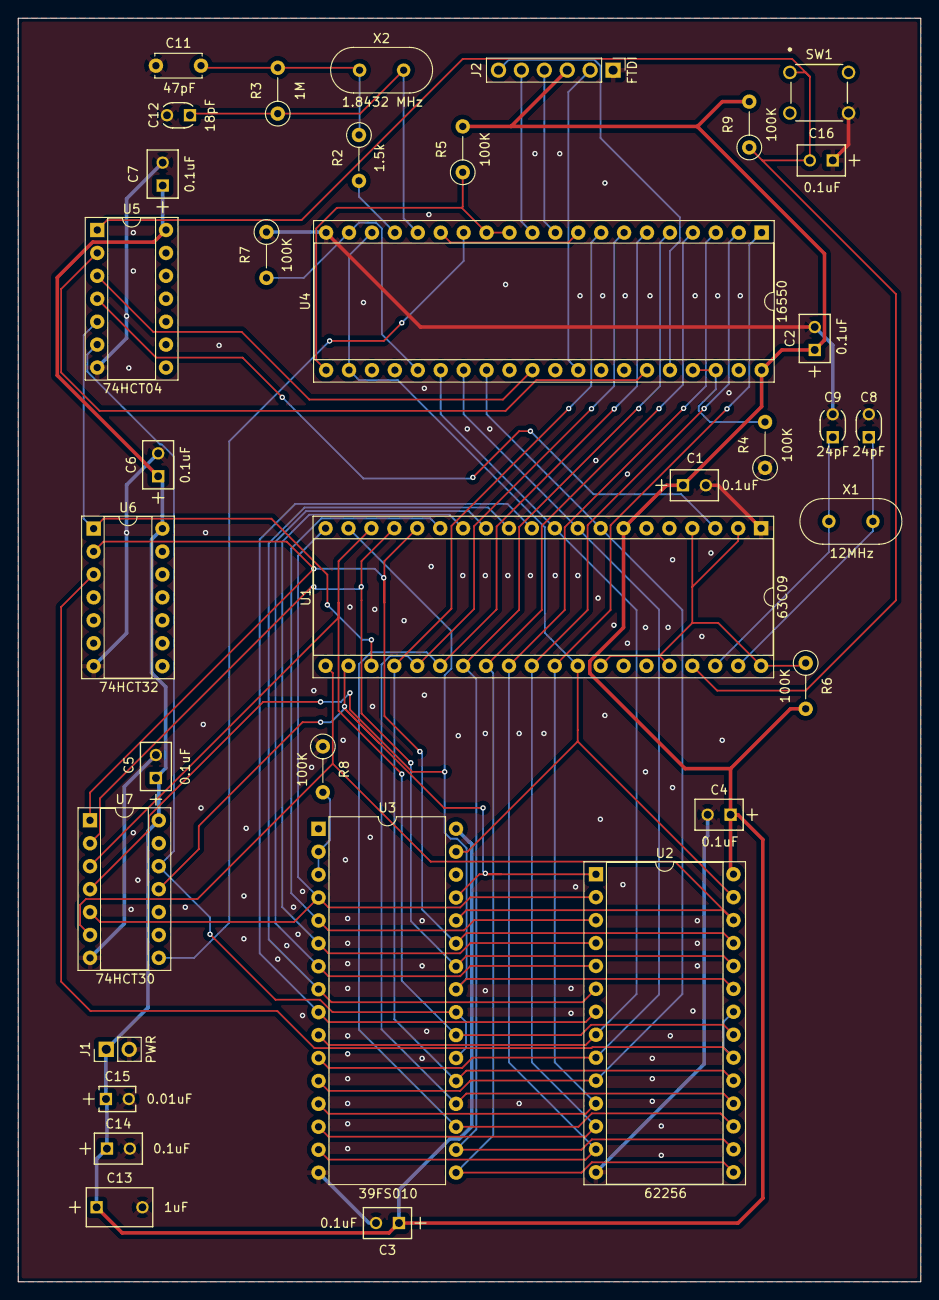
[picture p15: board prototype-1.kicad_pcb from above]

Board: 2 copper layers, 100.0 x 140.0 mm, 35 parts (0 on the bottom side), 49 nets.

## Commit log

2020-04-23 the function does not run every frame, just on every draw. fixed a few things
2020-05-05 got print working, new keyboard control converts keycode to char. all chars conv to charcodes using shiftMap and charMap. added temp cp/m logo cause fuck it
2020-05-15 copy all local files to repo
    cp/m files, sprites, circuit design
    [EDI2CAP.CFG, SN74LS273NE4.stl, SN74LS273NE4.stp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]
2020-05-15 remove SN74LS273NE4
    contains useless samacys libraries
    [EDI2CAP.CFG, SN74LS273NE4.stl, SN74LS273NE4.stp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]
2020-05-15 logo and first version of schematic
2021-05-13 start work on schematics
    [schematic.kicad_pcb, schematic.sch]
2021-05-19 delete gpl license
    GPL requires all works using this work be GPL compatible. I would rather allow my work to be used by all, even commercially. the MPL allows my work to be used commercially, as long as my work is still MPL. As a bonus, the MPL is not written by Richard Stallman.
2024-10-21 remove old schematics, add new ones
    [6809-board-prototype-1.kicad_pcb, 6809-board-prototype-1.kicad_sch, schematic.kicad_pcb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]
2024-10-22 updated readme to current plans
2024-10-23 add 16550 link, update readme, schematic work
2024-10-23 actually update the readme
    [6809-board-prototype-1.kicad_sch]
2024-10-23 VT82C42 info, schematic work. considering moving to cans
    [6809-board-prototype-1.kicad_sch]
2024-10-23 reset switch
    [6809-board-prototype-1.kicad_sch]
2024-10-23 set up serial port, new link
    [6809-board-prototype-1.kicad_sch]
2024-10-24 clocks on sch, 6809 datasheet, jameco xtals
    [6309-board-prototype-1.kicad_pro.kicad_sch]
2024-10-24 new datasheets, sch work, memory map
    [6309-board-prototype-1.kicad_pro.kicad_sch]
2024-10-24 almost done with schematic
    [6309-board-prototype-1.kicad_pro.kicad_sch]
2024-10-24 add footprints to schematic
    [6309-board-prototype-1.kicad_pro.kicad_pcb, 6309-board-prototype-1.kicad_pro.kicad_sch]
2024-10-28 changed rom, added correct switch, added a million footprints
    [6309-board-prototype-1.kicad_pro.kicad_pcb, 6309-board-prototype-1.kicad_pro.kicad_sch, bom.xlsx]
2024-10-31 switch from Tl16C550 to PC16550D due to availability
    [6309-board-prototype-1.kicad_pro.kicad_sch]
2024-10-31 fixed schematic, started pcb
    [6309-board-prototype-1.kicad_pro.kicad_pcb, 6309-board-prototype-1.kicad_pro.kicad_sch]
2024-10-31 pcb work
    [6309-board-prototype-1.kicad_pro.kicad_pcb]
2024-11-01 schematic work
    [6309-board-prototype-1.kicad_pro.kicad_pcb, 6309-board-prototype-1.kicad_pro.kicad_sch]
2024-11-05 pcb work, again
    [6309-board-prototype-1.kicad_pro.kicad_pcb]
2024-11-06 schematic work once again, getting close
    [6309-board-prototype-1.kicad_pro.kicad_pcb]
2024-11-08 fixed CTS/RTS and doubled width of power traces
    [6309-board-prototype-1.kicad_pro.kicad_pcb, 6309-board-prototype-1.kicad_pro.kicad_sch]
2024-11-14 pcb design finished, need to get reviewed
    [6309-board-prototype-1.kicad_pro.kicad_pcb]
2024-11-14 generate output files
    [6309-board-prototype-1.kicad_pro-B_Cu.gbr, 6309-board-prototype-1.kicad_pro-B_Mask.gbr, 6309-board-prototype-1.kicad_pro-B_Silkscreen.gbr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]
2024-11-14 add silkscreen text, re generate gerbers
    [6309-board-prototype-1.kicad_pro-B_Cu.gbr, 6309-board-prototype-1.kicad_pro-B_Mask.gbr, 6309-board-prototype-1.kicad_pro-B_Silkscreen.gbr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]
2024-11-14 fix dumbass mistake, re generate
    [6309-board-prototype-1.kicad_pro-B_Cu.gbr, 6309-board-prototype-1.kicad_pro-B_Mask.gbr, 6309-board-prototype-1.kicad_pro-B_Silkscreen.gbr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]
2024-11-15 remove excess vias
    [6309-board-prototype-1.kicad_pro-B_Cu.gbr, 6309-board-prototype-1.kicad_pro-B_Mask.gbr, 6309-board-prototype-1.kicad_pro-B_Silkscreen.gbr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]
2024-11-15 fix DRC errors
    [6309-board-prototype-1.kicad_pro-B_Cu.gbr, 6309-board-prototype-1.kicad_pro-B_Mask.gbr, 6309-board-prototype-1.kicad_pro-B_Silkscreen.gbr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]
2024-11-15 add ground connection to decoupling cap
    [6309-board-prototype-1.kicad_pro-B_Cu.gbr, 6309-board-prototype-1.kicad_pro-B_Mask.gbr, 6309-board-prototype-1.kicad_pro-B_Silkscreen.gbr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]
2024-11-19 add potential clock chip datasheet, fix gerber
2024-11-22 chore: organize pcb files
    [prototype-1-B_Cu.gbr, prototype-1-B_Mask.gbr, prototype-1-B_Silkscreen.gbr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]
2025-08-18 new pcb rev, fixes reset switch error
    [prototype-1.kicad_pcb, prototype-1.kicad_sch]
2025-08-21 new pcb cleanup
